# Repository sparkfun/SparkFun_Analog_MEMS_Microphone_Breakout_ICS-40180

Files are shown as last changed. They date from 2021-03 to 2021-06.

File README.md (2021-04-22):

SparkFun MEMS Microphone Breakout ICS-40180
========================================

SparkFun MEMS Microphone Breakout (ICS-40180) (https://www.sparkfun.com/products/18011)

[*SparkFun MEMS Microphone Breakout (ICS-40180) [BOB-18011]*](https://www.sparkfun.com/products/18011)

The SparkFun Analog MEMS Microphone Breakout makes it easy to work with the InvenSense ICS-40180 analog microphone. This board features an OpAmp to bring output of the microphone to a usable level, allowing you to plug directly into an ADC on a microcontroller or something like the [SparkFun Spectrum Shield](https://www.sparkfun.com/products/13116).

In addition to amplifying the signal, the OpAmp adds a bias voltage of 1/2 VCC. With sound sources such as a normal speaking voice a few feet away from the microphone, the AUD output signal will be at about 200mV peak-to-peak. Also note, this low profile microphone has its port on the bottom side, so the microphone can be mounted flush to the outer surface of your enclosure. This microphone is omni-directional, which means it does a good job of picking up sound sources from all directions.

Repository Contents
-------------------

* **/Documentation** - Data sheets, additional product information
* **/Hardware** - Eagle design files (.brd, .sch)
* **/Hardware/Production** - Production panel files (.brd)

Documentation
--------------
* **[Hookup Guide](https://learn.sparkfun.com/tutorials/mems-microphone-hookup-guide)** - Basic hookup guide for the SparkFun MEMS microphone breakout.

License Information
-------------------

This product is _**open source**_! 

Please review the LICENSE.md file for license information. 

If you have any questions or concerns on licensing, please contact technical support on our [SparkFun forums](https://forum.sparkfun.com/viewforum.php?f=152).

Distributed as-is; no warranty is given.

- Your friends at SparkFun.

_<COLLABORATION CREDIT>_

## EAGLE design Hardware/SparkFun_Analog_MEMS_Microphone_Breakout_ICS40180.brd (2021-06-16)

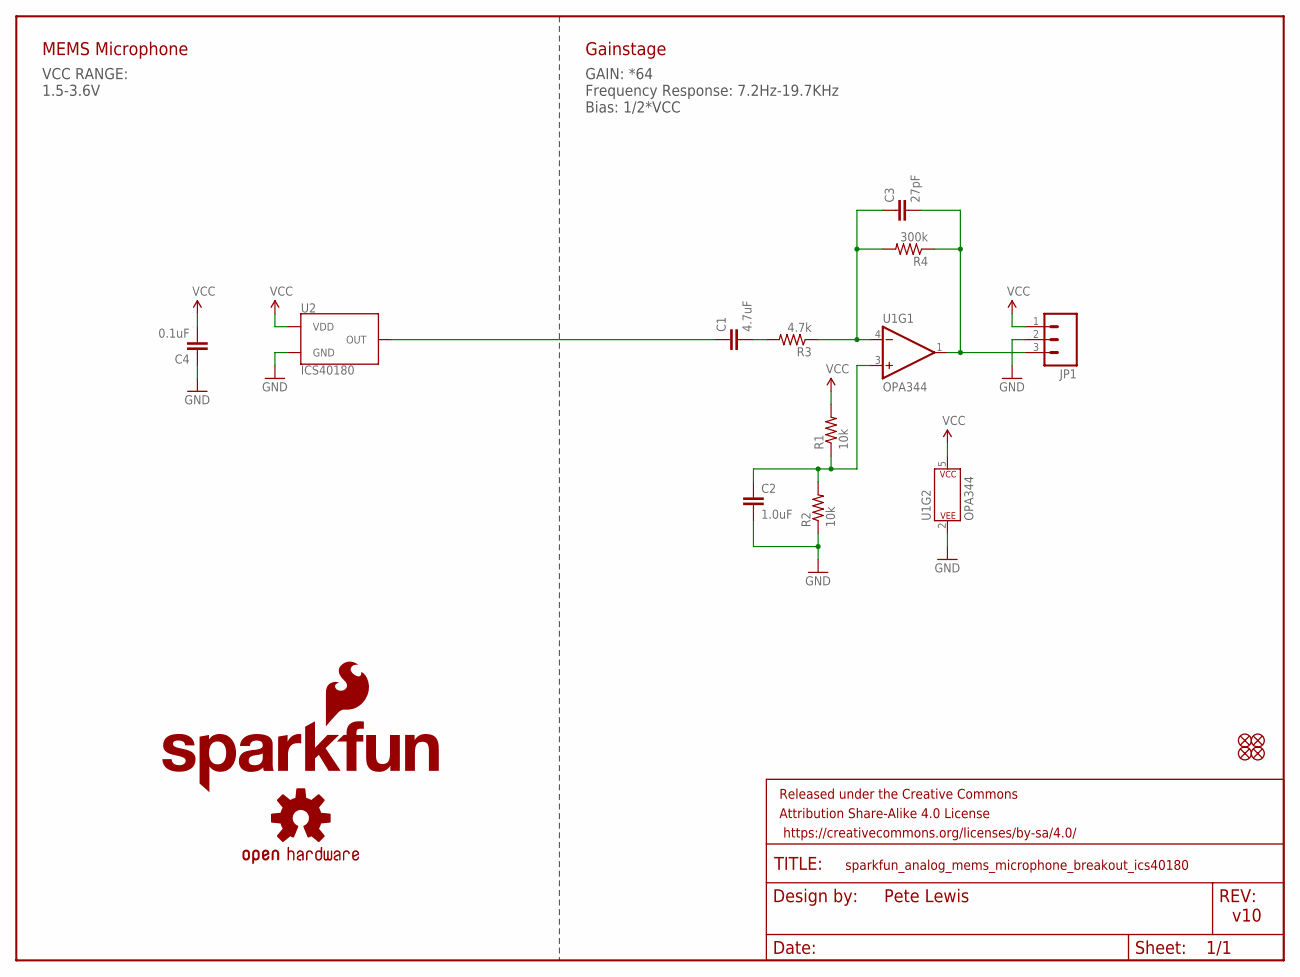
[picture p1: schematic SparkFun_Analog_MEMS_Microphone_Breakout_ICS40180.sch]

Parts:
C1: 4.7uF; 0603
C2: 1.0uF; 0603
C3: 27pF; 0603
C4: 0.1uF; 0603
FD1, FD2, FD3, FD4: FIDUCIALUFIDUCIAL; FIDUCIAL-MICRO
FRAME2: FRAME-LETTER; CREATIVE_COMMONS
JP1: CONN_031X03_NO_SILK; 1X03_NO_SILK
LOGO1: SFE_LOGO_FLAME.1_INCH; SFE_LOGO_FLAME_.1
LOGO2: OSHW-LOGOMINI; OSHW-LOGO-MINI
R1, R2: 10k; 0603
R3: 4.7k; 0603
R4: 300k; 0603
U1: OPA344; SOT23-5
U2: ICS40180

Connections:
AUD: C3.2, JP1.3, R4.1, U1.1 (OUT)
GND: C2.2, C4.1, JP1.2, R2.1, U1.2 (P$V-), U2.2 (GND), U2.3 (GND), U2.4 (GND)
unnamed: C1.1, U2.1 (OUT)
unnamed: C3.1, R3.1, R4.2, U1.4 (-IN)
unnamed: C1.2, R3.2
unnamed: C2.1, R1.1, R2.2, U1.3 (+IN)
VCC: C4.2, JP1.1, R1.2, U1.5 (P$V+), U2.5 (VDD)

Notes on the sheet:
v10
Pete Lewis
VCC RANGE: 1.5-3.6V
MEMS Microphone
Gainstage
GAIN: *64 Frequency Response: 7.2Hz-19.7KHz Bias: 1/2*VCC

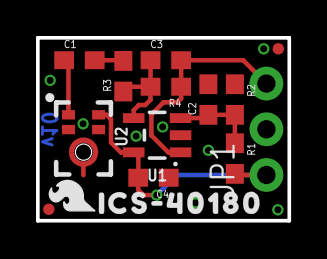
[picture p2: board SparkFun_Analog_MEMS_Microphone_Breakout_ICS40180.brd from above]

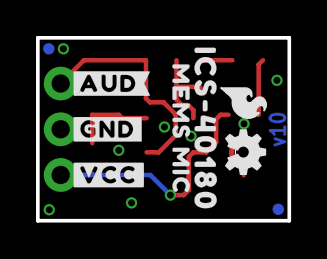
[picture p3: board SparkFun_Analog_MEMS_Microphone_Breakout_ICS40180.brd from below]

Board: 2 copper layers, 14.0 x 10.2 mm, 25 parts (9 on the bottom side), 7 nets.

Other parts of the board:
LOGO3: SFE_LOGO_FLAME.1_INCH; SFE_LOGO_FLAME_.1
U$1, U$6: ICS#401800
U$2: MEMS_MIC0
U$3: #GND#0
U$4: #VCC#0
U$5: #AUD#0

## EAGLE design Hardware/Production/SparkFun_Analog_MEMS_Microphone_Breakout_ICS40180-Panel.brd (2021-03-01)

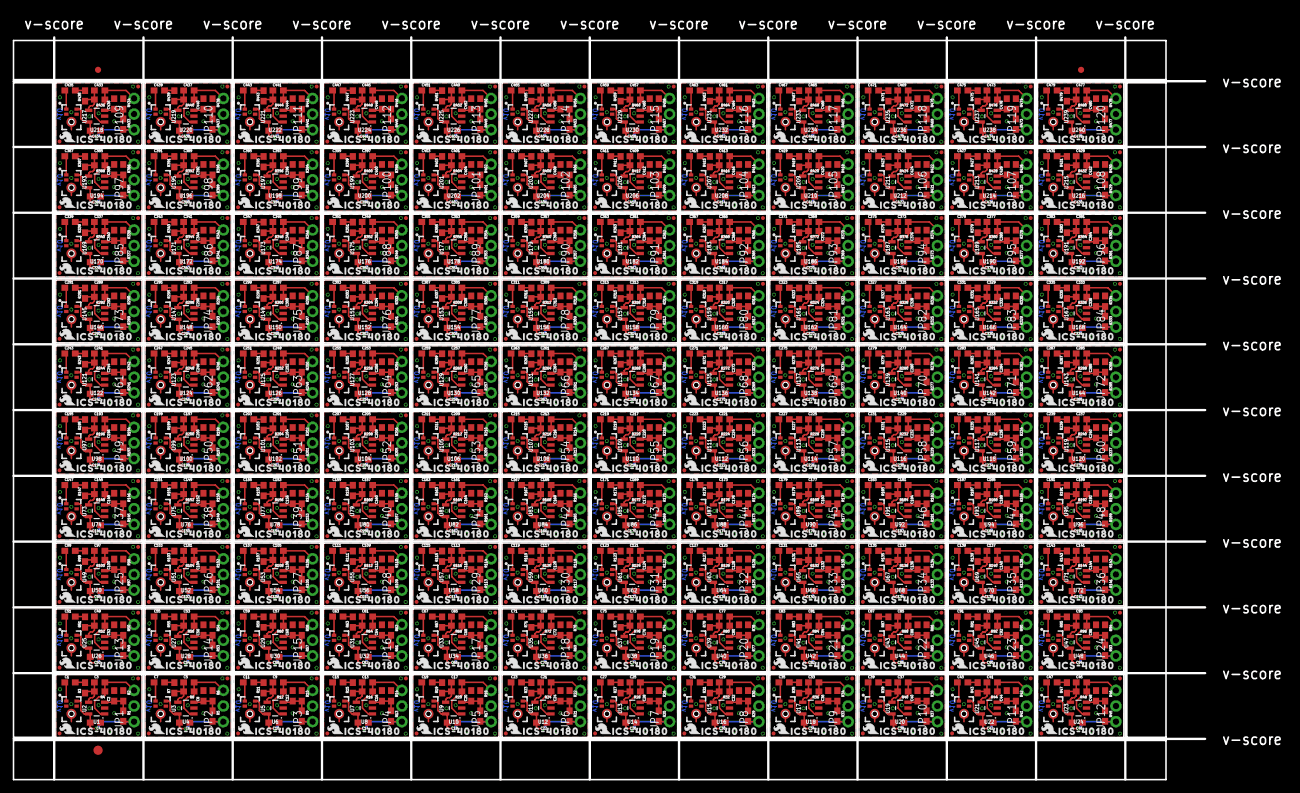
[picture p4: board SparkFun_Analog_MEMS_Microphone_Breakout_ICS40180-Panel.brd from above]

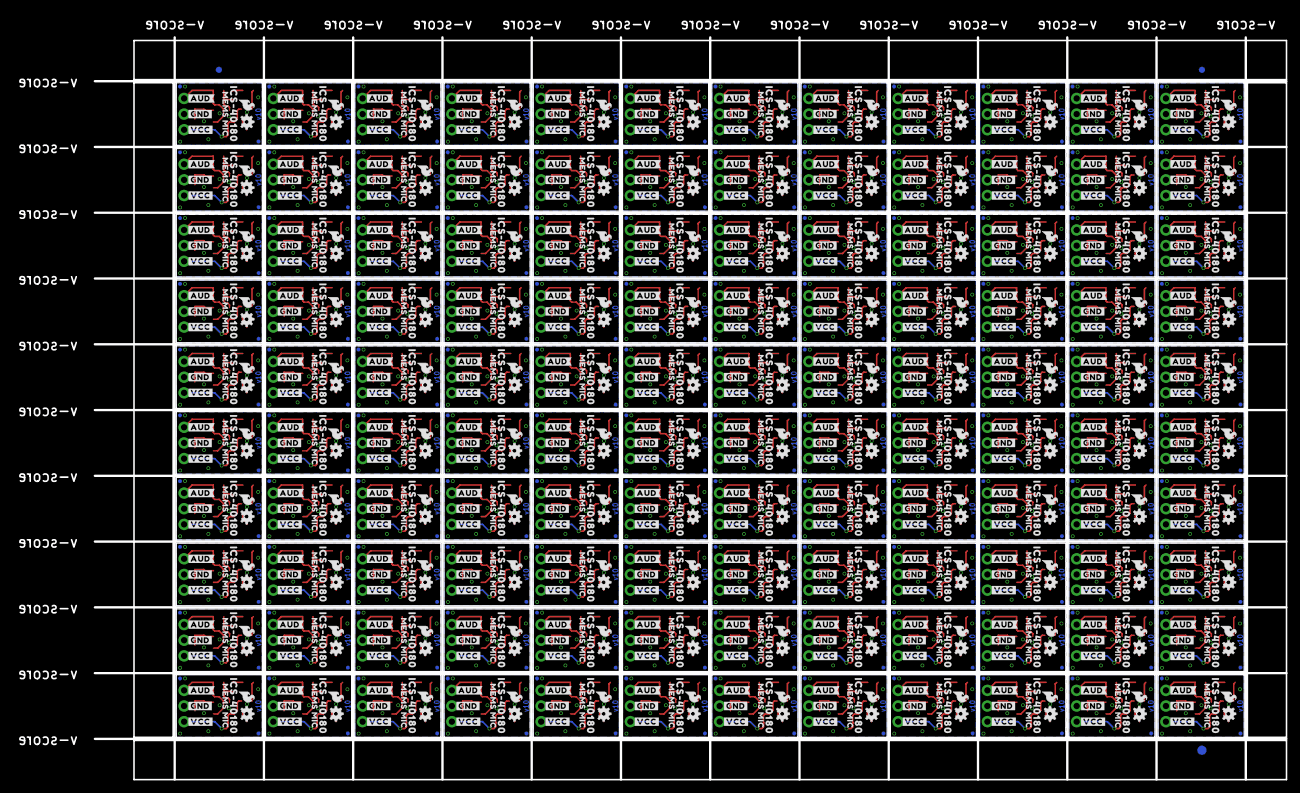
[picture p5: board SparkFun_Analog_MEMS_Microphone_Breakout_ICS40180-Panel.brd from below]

Board: 2 copper layers, 193.3 x 120.4 mm, 2886 parts (1083 on the bottom side), 840 nets.

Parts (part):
C1, C7, C11, C15, C19, C23, C27, C31, C35, C39, C43, C47, C51, C55, C59, C63, C67, C71, C75, C79, C83, C87, C91, C95, C99, C103, C107, C111, C115, C119, C123, C127, C131, C135, C139, C143, C147, C151, C155, C159, C163, C167, C171, C175, C179, C183, C187, C191, C195, C199, C203, C207, C211, C215, C219, C223, C227, C231, C235, C239, C243, C247, C251, C255, C259, C263, C267, C271, C275, C279, C283, C287, C291, C295, C299, C303, C307, C311, C315, C319, C323, C327, C331, C335, C339, C343, C347, C351, C355, C359, C363, C367, C371, C375, C379, C383, C387, C391, C395, C399, C403, C407, C411, C415, C419, C423, C427, C431, C435, C439, C443, C447, C451, C455, C459, C463, C467, C471, C475, C479: 4.7uF; 0603
C2, C8, C12, C16, C20, C24, C28, C32, C36, C40, C44, C48, C52, C56, C60, C64, C68, C72, C76, C80, C84, C88, C92, C96, C100, C104, C108, C112, C116, C120, C124, C128, C132, C136, C140, C144, C148, C152, C156, C160, C164, C168, C172, C176, C180, C184, C188, C192, C196, C200, C204, C208, C212, C216, C220, C224, C228, C232, C236, C240, C244, C248, C252, C256, C260, C264, C268, C272, C276, C280, C284, C288, C292, C296, C300, C304, C308, C312, C316, C320, C324, C328, C332, C336, C340, C344, C348, C352, C356, C360, C364, C368, C372, C376, C380, C384, C388, C392, C396, C400, C404, C408, C412, C416, C420, C424, C428, C432, C436, C440, C444, C448, C452, C456, C460, C464, C468, C472, C476, C480: 1.0uF; 0603
C3, C5, C9, C13, C17, C21, C25, C29, C33, C37, C41, C45, C49, C53, C57, C61, C65, C69, C73, C77, C81, C85, C89, C93, C97, C101, C105, C109, C113, C117, C121, C125, C129, C133, C137, C141, C145, C149, C153, C157, C161, C165, C169, C173, C177, C181, C185, C189, C193, C197, C201, C205, C209, C213, C217, C221, C225, C229, C233, C237, C241, C245, C249, C253, C257, C261, C265, C269, C273, C277, C281, C285, C289, C293, C297, C301, C305, C309, C313, C317, C321, C325, C329, C333, C337, C341, C345, C349, C353, C357, C361, C365, C369, C373, C377, C381, C385, C389, C393, C397, C401, C405, C409, C413, C417, C421, C425, C429, C433, C437, C441, C445, C449, C453, C457, C461, C465, C469, C473, C477: 27pF; 0603
C4, C6, C10, C14, C18, C22, C26, C30, C34, C38, C42, C46, C50, C54, C58, C62, C66, C70, C74, C78, C82, C86, C90, C94, C98, C102, C106, C110, C114, C118, C122, C126, C130, C134, C138, C142, C146, C150, C154, C158, C162, C166, C170, C174, C178, C182, C186, C190, C194, C198, C202, C206, C210, C214, C218, C222, C226, C230, C234, C238, C242, C246, C250, C254, C258, C262, C266, C270, C274, C278, C282, C286, C290, C294, C298, C302, C306, C310, C314, C318, C322, C326, C330, C334, C338, C342, C346, C350, C354, C358, C362, C366, C370, C374, C378, C382, C386, C390, C394, C398, C402, C406, C410, C414, C418, C422, C426, C430, C434, C438, C442, C446, C450, C454, C458, C462, C466, C470, C474, C478: 0.1uF; 0603
E$1, E$2, E$3, E$4: FIDUCIAL-1X2
E$5, E$6: FIDUCIAL-1.5X3
FD1, FD2, FD3, FD4, FD5, FD6, FD7, FD8, FD9, FD10, FD11, FD12, FD13, FD14, FD15, FD16, FD17, FD18, FD19, FD20, FD21, FD22, FD23, FD24, FD25, FD26, FD27, FD28, FD29, FD30, FD31, FD32, FD33, FD34, FD35, FD36, FD37, FD38, FD39, FD40, FD41, FD42, FD43, FD44, FD45, FD46, FD47, FD48, FD49, FD50, FD51, FD52, FD53, FD54, FD55, FD56, FD57, FD58, FD59, FD60, FD61, FD62, FD63, FD64, FD65, FD66, FD67, FD68, FD69, FD70, FD71, FD72, FD73, FD74, FD75, FD76, FD77, FD78, FD79, FD80, FD81, FD82, FD83, FD84, FD85, FD86, FD87, FD88, FD89, FD90, FD91, FD92, FD93, FD94, FD95, FD96, FD97, FD98, FD99, FD100, FD101, FD102, FD103, FD104, FD105, FD106, FD107, FD108, FD109, FD110, FD111, FD112, FD113, FD114, FD115, FD116, FD117, FD118, FD119, FD120, FD121, FD122, FD123, FD124, FD125, FD126, FD127, FD128, FD129, FD130, FD131, FD132, FD133, FD134, FD135, FD136, FD137, FD138, FD139, FD140, FD141, FD142, FD143, FD144, FD145, FD146, FD147, FD148, FD149, FD150, FD151, FD152, FD153, FD154, FD155, FD156, FD157, FD158, FD159, FD160, FD161, FD162, FD163, FD164, FD165, FD166, FD167, FD168, FD169, FD170, FD171, FD172, FD173, FD174, FD175, FD176, FD177, FD178, FD179, FD180, FD181, FD182, FD183, FD184, FD185, FD186, FD187, FD188, FD189, FD190, FD191, FD192, FD193, FD194, FD195, FD196, FD197, FD198, FD199, FD200, FD201, FD202, FD203, FD204, FD205, FD206, FD207, FD208, FD209, FD210, FD211, FD212, FD213, FD214, FD215, FD216, FD217, FD218, FD219, FD220, FD221, FD222, FD223, FD224, FD225, FD226, FD227, FD228, FD229, FD230, FD231, FD232, FD233, FD234, FD235, FD236, FD237, FD238, FD239, FD240, FD241, FD242, FD243, FD244, FD245, FD246, FD247, FD248, FD249, FD250, FD251, FD252, FD253, FD254, FD255, FD256, FD257, FD258, FD259, FD260, FD261, FD262, FD263, FD264, FD265, FD266, FD267, FD268, FD269, FD270, FD271, FD272, FD273, FD274, FD275, FD276, FD277, FD278, FD279, FD280, FD281, FD282, FD283, FD284, FD285, FD286, FD287, FD288, FD289, FD290, FD291, FD292, FD293, FD294, FD295, FD296, FD297, FD298, FD299, FD300, FD301, FD302, FD303, FD304, FD305, FD306, FD307, FD308, FD309, FD310, FD311, FD312, FD313, FD314, FD315, FD316, FD317, FD318, FD319, FD320, FD321, FD322, FD323, FD324, FD325, FD326, FD327, FD328, FD329, FD330, FD331, FD332, FD333, FD334, FD335, FD336, FD337, FD338, FD339, FD340, FD341, FD342, FD343, FD344, FD345, FD346, FD347, FD348, FD349, FD350, FD351, FD352, FD353, FD354, FD355, FD356, FD357, FD358, FD359, FD360, FD361, FD362, FD363, FD364, FD365, FD366, FD367, FD368, FD369, FD370, FD371, FD372, FD373, FD374, FD375, FD376, FD377, FD378, FD379, FD380, FD381, FD382, FD383, FD384, FD385, FD386, FD387, FD388, FD389, FD390, FD391, FD392, FD393, FD394, FD395, FD396, FD397, FD398, FD399, FD400, FD401, FD402, FD403, FD404, FD405, FD406, FD407, FD408, FD409, FD410, FD411, FD412, FD413, FD414, FD415, FD416, FD417, FD418, FD419, FD420, FD421, FD422, FD423, FD424, FD425, FD426, FD427, FD428, FD429, FD430, FD431, FD432, FD433, FD434, FD435, FD436, FD437, FD438, FD439, FD440, FD441, FD442, FD443, FD444, FD445, FD446, FD447, FD448, FD449, FD450, FD451, FD452, FD453, FD454, FD455, FD456, FD457, FD458, FD459, FD460, FD461, FD462, FD463, FD464, FD465, FD466, FD467, FD468, FD469, FD470, FD471, FD472, FD473, FD474, FD475, FD476, FD477, FD478, FD479, FD480: FIDUCIALUFIDUCIAL; FIDUCIAL-MICRO
JP1, JP2, JP3, JP4, JP5, JP6, JP7, JP8, JP9, JP10, JP11, JP12, JP13, JP14, JP15, JP16, JP17, JP18, JP19, JP20, JP21, JP22, JP23, JP24, JP25, JP26, JP27, JP28, JP29, JP30, JP31, JP32, JP33, JP34, JP35, JP36, JP37, JP38, JP39, JP40, JP41, JP42, JP43, JP44, JP45, JP46, JP47, JP48, JP49, JP50, JP51, JP52, JP53, JP54, JP55, JP56, JP57, JP58, JP59, JP60, JP61, JP62, JP63, JP64, JP65, JP66, JP67, JP68, JP69, JP70, JP71, JP72, JP73, JP74, JP75, JP76, JP77, JP78, JP79, JP80, JP81, JP82, JP83, JP84, JP85, JP86, JP87, JP88, JP89, JP90, JP91, JP92, JP93, JP94, JP95, JP96, JP97, JP98, JP99, JP100, JP101, JP102, JP103, JP104, JP105, JP106, JP107, JP108, JP109, JP110, JP111, JP112, JP113, JP114, JP115, JP116, JP117, JP118, JP119, JP120: 1X03_NO_SILK
LOGO1, LOGO3, LOGO4, LOGO6, LOGO7, LOGO9, LOGO10, LOGO12, LOGO13, LOGO15, LOGO16, LOGO18, LOGO19, LOGO21, LOGO22, LOGO24, LOGO25, LOGO27, LOGO28, LOGO30, LOGO31, LOGO33, LOGO34, LOGO36, LOGO37, LOGO39, LOGO40, LOGO42, LOGO43, LOGO45, LOGO46, LOGO48, LOGO49, LOGO51, LOGO52, LOGO54, LOGO55, LOGO57, LOGO58, LOGO60, LOGO61, LOGO63, LOGO64, LOGO66, LOGO67, LOGO69, LOGO70, LOGO72, LOGO73, LOGO75, LOGO76, LOGO78, LOGO79, LOGO81, LOGO82, LOGO84, LOGO85, LOGO87, LOGO88, LOGO90, LOGO91, LOGO93, LOGO94, LOGO96, LOGO97, LOGO99, LOGO100, LOGO102, LOGO103, LOGO105, LOGO106, LOGO108, LOGO109, LOGO111, LOGO112, LOGO114, LOGO115, LOGO117, LOGO118, LOGO120, LOGO121, LOGO123, LOGO124, LOGO126, LOGO127, LOGO129, LOGO130, LOGO132, LOGO133, LOGO135, LOGO136, LOGO138, LOGO139, LOGO141, LOGO142, LOGO144, LOGO145, LOGO147, LOGO148, LOGO150, LOGO151, LOGO153, LOGO154, LOGO156, LOGO157, LOGO159, LOGO160, LOGO162, LOGO163, LOGO165, LOGO166, LOGO168, LOGO169, LOGO171, LOGO172, LOGO174, LOGO175, LOGO177, LOGO178, LOGO180, LOGO181, LOGO183, LOGO184, LOGO186, LOGO187, LOGO189, LOGO190, LOGO192, LOGO193, LOGO195, LOGO196, LOGO198, LOGO199, LOGO201, LOGO202, LOGO204, LOGO205, LOGO207, LOGO208, LOGO210, LOGO211, LOGO213, LOGO214, LOGO216, LOGO217, LOGO219, LOGO220, LOGO222, LOGO223, LOGO225, LOGO226, LOGO228, LOGO229, LOGO231, LOGO232, LOGO234, LOGO235, LOGO237, LOGO238, LOGO240, LOGO241, LOGO243, LOGO244, LOGO246, LOGO247, LOGO249, LOGO250, LOGO252, LOGO253, LOGO255, LOGO256, LOGO258, LOGO259, LOGO261, LOGO262, LOGO264, LOGO265, LOGO267, LOGO268, LOGO270, LOGO271, LOGO273, LOGO274, LOGO276, LOGO277, LOGO279, LOGO280, LOGO282, LOGO283, LOGO285, LOGO286, LOGO288, LOGO289, LOGO291, LOGO292, LOGO294, LOGO295, LOGO297, LOGO298, LOGO300, LOGO301, LOGO303, LOGO304, LOGO306, LOGO307, LOGO309, LOGO310, LOGO312, LOGO313, LOGO315, LOGO316, LOGO318, LOGO319, LOGO321, LOGO322, LOGO324, LOGO325, LOGO327, LOGO328, LOGO330, LOGO331, LOGO333, LOGO334, LOGO336, LOGO337, LOGO339, LOGO340, LOGO342, LOGO343, LOGO345, LOGO346, LOGO348, LOGO349, LOGO351, LOGO352, LOGO354, LOGO355, LOGO357, LOGO358, LOGO360: SFE_LOGO_FLAME.1_INCH; SFE_LOGO_FLAME_.1
LOGO2, LOGO5, LOGO8, LOGO11, LOGO14, LOGO17, LOGO20, LOGO23, LOGO26, LOGO29, LOGO32, LOGO35, LOGO38, LOGO41, LOGO44, LOGO47, LOGO50, LOGO53, LOGO56, LOGO59, LOGO62, LOGO65, LOGO68, LOGO71, LOGO74, LOGO77, LOGO80, LOGO83, LOGO86, LOGO89, LOGO92, LOGO95, LOGO98, LOGO101, LOGO104, LOGO107, LOGO110, LOGO113, LOGO116, LOGO119, LOGO122, LOGO125, LOGO128, LOGO131, LOGO134, LOGO137, LOGO140, LOGO143, LOGO146, LOGO149, LOGO152, LOGO155, LOGO158, LOGO161, LOGO164, LOGO167, LOGO170, LOGO173, LOGO176, LOGO179, LOGO182, LOGO185, LOGO188, LOGO191, LOGO194, LOGO197, LOGO200, LOGO203, LOGO206, LOGO209, LOGO212, LOGO215, LOGO218, LOGO221, LOGO224, LOGO227, LOGO230, LOGO233, LOGO236, LOGO239, LOGO242, LOGO245, LOGO248, LOGO251, LOGO254, LOGO257, LOGO260, LOGO263, LOGO266, LOGO269, LOGO272, LOGO275, LOGO278, LOGO281, LOGO284, LOGO287, LOGO290, LOGO293, LOGO296, LOGO299, LOGO302, LOGO305, LOGO308, LOGO311, LOGO314, LOGO317, LOGO320, LOGO323, LOGO326, LOGO329, LOGO332, LOGO335, LOGO338, LOGO341, LOGO344, LOGO347, LOGO350, LOGO353, LOGO356, LOGO359: OSHW-LOGOMINI; OSHW-LOGO-MINI
R1, R2, R5, R6, R9, R10, R13, R14, R17, R18, R21, R22, R25, R26, R29, R30, R33, R34, R37, R38, R41, R42, R45, R46, R49, R50, R53, R54, R57, R58, R61, R62, R65, R66, R69, R70, R73, R74, R77, R78, R81, R82, R85, R86, R89, R90, R93, R94, R97, R98, R101, R102, R105, R106, R109, R110, R113, R114, R117, R118, R121, R122, R125, R126, R129, R130, R133, R134, R137, R138, R141, R142, R145, R146, R149, R150, R153, R154, R157, R158, R161, R162, R165, R166, R169, R170, R173, R174, R177, R178, R181, R182, R185, R186, R189, R190, R193, R194, R197, R198, R201, R202, R205, R206, R209, R210, R213, R214, R217, R218, R221, R222, R225, R226, R229, R230, R233, R234, R237, R238, R241, R242, R245, R246, R249, R250, R253, R254, R257, R258, R261, R262, R265, R266, R269, R270, R273, R274, R277, R278, R281, R282, R285, R286, R289, R290, R293, R294, R297, R298, R301, R302, R305, R306, R309, R310, R313, R314, R317, R318, R321, R322, R325, R326, R329, R330, R333, R334, R337, R338, R341, R342, R345, R346, R349, R350, R353, R354, R357, R358, R361, R362, R365, R366, R369, R370, R373, R374, R377, R378, R381, R382, R385, R386, R389, R390, R393, R394, R397, R398, R401, R402, R405, R406, R409, R410, R413, R414, R417, R418, R421, R422, R425, R426, R429, R430, R433, R434, R437, R438, R441, R442, R445, R446, R449, R450, R453, R454, R457, R458, R461, R462, R465, R466, R469, R470, R473, R474, R477, R478: 10k; 0603
R3, R7, R11, R15, R19, R23, R27, R31, R35, R39, R43, R47, R51, R55, R59, R63, R67, R71, R75, R79, R83, R87, R91, R95, R99, R103, R107, R111, R115, R119, R123, R127, R131, R135, R139, R143, R147, R151, R155, R159, R163, R167, R171, R175, R179, R183, R187, R191, R195, R199, R203, R207, R211, R215, R219, R223, R227, R231, R235, R239, R243, R247, R251, R255, R259, R263, R267, R271, R275, R279, R283, R287, R291, R295, R299, R303, R307, R311, R315, R319, R323, R327, R331, R335, R339, R343, R347, R351, R355, R359, R363, R367, R371, R375, R379, R383, R387, R391, R395, R399, R403, R407, R411, R415, R419, R423, R427, R431, R435, R439, R443, R447, R451, R455, R459, R463, R467, R471, R475, R479: 4.7k; 0603
R4, R8, R12, R16, R20, R24, R28, R32, R36, R40, R44, R48, R52, R56, R60, R64, R68, R72, R76, R80, R84, R88, R92, R96, R100, R104, R108, R112, R116, R120, R124, R128, R132, R136, R140, R144, R148, R152, R156, R160, R164, R168, R172, R176, R180, R184, R188, R192, R196, R200, R204, R208, R212, R216, R220, R224, R228, R232, R236, R240, R244, R248, R252, R256, R260, R264, R268, R272, R276, R280, R284, R288, R292, R296, R300, R304, R308, R312, R316, R320, R324, R328, R332, R336, R340, R344, R348, R352, R356, R360, R364, R368, R372, R376, R380, R384, R388, R392, R396, R400, R404, R408, R412, R416, R420, R424, R428, R432, R436, R440, R444, R448, R452, R456, R460, R464, R468, R472, R476, R480: 300k; 0603
U1, U4, U6, U8, U10, U12, U14, U16, U18, U20, U22, U24, U26, U28, U30, U32, U34, U36, U38, U40, U42, U44, U46, U48, U50, U52, U54, U56, U58, U60, U62, U64, U66, U68, U70, U72, U74, U76, U78, U80, U82, U84, U86, U88, U90, U92, U94, U96, U98, U100, U102, U104, U106, U108, U110, U112, U114, U116, U118, U120, U122, U124, U126, U128, U130, U132, U134, U136, U138, U140, U142, U144, U146, U148, U150, U152, U154, U156, U158, U160, U162, U164, U166, U168, U170, U172, U174, U176, U178, U180, U182, U184, U186, U188, U190, U192, U194, U196, U198, U200, U202, U204, U206, U208, U210, U212, U214, U216, U218, U220, U222, U224, U226, U228, U230, U232, U234, U236, U238, U240: OPA344; SOT23-5
U2, U3, U5, U7, U9, U11, U13, U15, U17, U19, U21, U23, U25, U27, U29, U31, U33, U35, U37, U39, U41, U43, U45, U47, U49, U51, U53, U55, U57, U59, U61, U63, U65, U67, U69, U71, U73, U75, U77, U79, U81, U83, U85, U87, U89, U91, U93, U95, U97, U99, U101, U103, U105, U107, U109, U111, U113, U115, U117, U119, U121, U123, U125, U127, U129, U131, U133, U135, U137, U139, U141, U143, U145, U147, U149, U151, U153, U155, U157, U159, U161, U163, U165, U167, U169, U171, U173, U175, U177, U179, U181, U183, U185, U187, U189, U191, U193, U195, U197, U199, U201, U203, U205, U207, U209, U211, U213, U215, U217, U219, U221, U223, U225, U227, U229, U231, U233, U235, U237, U239: ICS40180
U$1, U$6, U$7, U$12, U$13, U$18, U$19, U$24, U$25, U$30, U$31, U$36, U$37, U$42, U$43, U$48, U$49, U$54, U$55, U$60, U$61, U$66, U$67, U$72, U$73, U$78, U$79, U$84, U$85, U$90, U$91, U$96, U$97, U$102, U$103, U$108, U$109, U$114, U$115, U$120, U$121, U$126, U$127, U$132, U$133, U$138, U$139, U$144, U$145, U$150, U$151, U$156, U$157, U$162, U$163, U$168, U$169, U$174, U$175, U$180, U$181, U$186, U$187, U$192, U$193, U$198, U$199, U$204, U$205, U$210, U$211, U$216, U$217, U$222, U$223, U$228, U$229, U$234, U$235, U$240, U$241, U$246, U$247, U$252, U$253, U$258, U$259, U$264, U$265, U$270, U$271, U$276, U$277, U$282, U$283, U$288, U$289, U$294, U$295, U$300, U$301, U$306, U$307, U$312, U$313, U$318, U$319, U$324, U$325, U$330, U$331, U$336, U$337, U$342, U$343, U$348, U$349, U$354, U$355, U$360, U$361, U$366, U$367, U$372, U$373, U$378, U$379, U$384, U$385, U$390, U$391, U$396, U$397, U$402, U$403, U$408, U$409, U$414, U$415, U$420, U$421, U$426, U$427, U$432, U$433, U$438, U$439, U$444, U$445, U$450, U$451, U$456, U$457, U$462, U$463, U$468, U$469, U$474, U$475, U$480, U$481, U$486, U$487, U$492, U$493, U$498, U$499, U$504, U$505, U$510, U$511, U$516, U$517, U$522, U$523, U$528, U$529, U$534, U$535, U$540, U$541, U$546, U$547, U$552, U$553, U$558, U$559, U$564, U$565, U$570, U$571, U$576, U$577, U$582, U$583, U$588, U$589, U$594, U$595, U$600, U$601, U$606, U$607, U$612, U$613, U$618, U$619, U$624, U$625, U$630, U$631, U$636, U$637, U$642, U$643, U$648, U$649, U$654, U$655, U$660, U$661, U$666, U$667, U$672, U$673, U$678, U$679, U$684, U$685, U$690, U$691, U$696, U$697, U$702, U$703, U$708, U$709, U$714, U$715, U$720: ICS#401800
U$2, U$8, U$14, U$20, U$26, U$32, U$38, U$44, U$50, U$56, U$62, U$68, U$74, U$80, U$86, U$92, U$98, U$104, U$110, U$116, U$122, U$128, U$134, U$140, U$146, U$152, U$158, U$164, U$170, U$176, U$182, U$188, U$194, U$200, U$206, U$212, U$218, U$224, U$230, U$236, U$242, U$248, U$254, U$260, U$266, U$272, U$278, U$284, U$290, U$296, U$302, U$308, U$314, U$320, U$326, U$332, U$338, U$344, U$350, U$356, U$362, U$368, U$374, U$380, U$386, U$392, U$398, U$404, U$410, U$416, U$422, U$428, U$434, U$440, U$446, U$452, U$458, U$464, U$470, U$476, U$482, U$488, U$494, U$500, U$506, U$512, U$518, U$524, U$530, U$536, U$542, U$548, U$554, U$560, U$566, U$572, U$578, U$584, U$590, U$596, U$602, U$608, U$614, U$620, U$626, U$632, U$638, U$644, U$650, U$656, U$662, U$668, U$674, U$680, U$686, U$692, U$698, U$704, U$710, U$716: MEMS_MIC0
U$3, U$9, U$15, U$21, U$27, U$33, U$39, U$45, U$51, U$57, U$63, U$69, U$75, U$81, U$87, U$93, U$99, U$105, U$111, U$117, U$123, U$129, U$135, U$141, U$147, U$153, U$159, U$165, U$171, U$177, U$183, U$189, U$195, U$201, U$207, U$213, U$219, U$225, U$231, U$237, U$243, U$249, U$255, U$261, U$267, U$273, U$279, U$285, U$291, U$297, U$303, U$309, U$315, U$321, U$327, U$333, U$339, U$345, U$351, U$357, U$363, U$369, U$375, U$381, U$387, U$393, U$399, U$405, U$411, U$417, U$423, U$429, U$435, U$441, U$447, U$453, U$459, U$465, U$471, U$477, U$483, U$489, U$495, U$501, U$507, U$513, U$519, U$525, U$531, U$537, U$543, U$549, U$555, U$561, U$567, U$573, U$579, U$585, U$591, U$597, U$603, U$609, U$615, U$621, U$627, U$633, U$639, U$645, U$651, U$657, U$663, U$669, U$675, U$681, U$687, U$693, U$699, U$705, U$711, U$717: #GND#0
U$4, U$10, U$16, U$22, U$28, U$34, U$40, U$46, U$52, U$58, U$64, U$70, U$76, U$82, U$88, U$94, U$100, U$106, U$112, U$118, U$124, U$130, U$136, U$142, U$148, U$154, U$160, U$166, U$172, U$178, U$184, U$190, U$196, U$202, U$208, U$214, U$220, U$226, U$232, U$238, U$244, U$250, U$256, U$262, U$268, U$274, U$280, U$286, U$292, U$298, U$304, U$310, U$316, U$322, U$328, U$334, U$340, U$346, U$352, U$358, U$364, U$370, U$376, U$382, U$388, U$394, U$400, U$406, U$412, U$418, U$424, U$430, U$436, U$442, U$448, U$454, U$460, U$466, U$472, U$478, U$484, U$490, U$496, U$502, U$508, U$514, U$520, U$526, U$532, U$538, U$544, U$550, U$556, U$562, U$568, U$574, U$580, U$586, U$592, U$598, U$604, U$610, U$616, U$622, U$628, U$634, U$640, U$646, U$652, U$658, U$664, U$670, U$676, U$682, U$688, U$694, U$700, U$706, U$712, U$718: #VCC#0
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

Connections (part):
AUD: C3.2, JP1.3, R4.1, U1.1
AUD1: C5.2, JP2.3, R8.1, U4.1
AUD2: C9.2, JP3.3, R12.1, U6.1
AUD3: C13.2, JP4.3, R16.1, U8.1
AUD4: C17.2, JP5.3, R20.1, U10.1
AUD5: C21.2, JP6.3, R24.1, U12.1
AUD6: C25.2, JP7.3, R28.1, U14.1
AUD7: C29.2, JP8.3, R32.1, U16.1
AUD8: C33.2, JP9.3, R36.1, U18.1
AUD9: C37.2, JP10.3, R40.1, U20.1
AUD10: C41.2, JP11.3, R44.1, U22.1
AUD11: C45.2, JP12.3, R48.1, U24.1
AUD12: C49.2, JP13.3, R52.1, U26.1
AUD13: C53.2, JP14.3, R56.1, U28.1
AUD14: C57.2, JP15.3, R60.1, U30.1
AUD15: C61.2, JP16.3, R64.1, U32.1
AUD16: C65.2, JP17.3, R68.1, U34.1
AUD17: C69.2, JP18.3, R72.1, U36.1
AUD18: C73.2, JP19.3, R76.1, U38.1
AUD19: C77.2, JP20.3, R80.1, U40.1
AUD20: C81.2, JP21.3, R84.1, U42.1
AUD21: C85.2, JP22.3, R88.1, U44.1
AUD22: C89.2, JP23.3, R92.1, U46.1
AUD23: C93.2, JP24.3, R96.1, U48.1
AUD24: C97.2, JP25.3, R100.1, U50.1
AUD25: C101.2, JP26.3, R104.1, U52.1
AUD26: C105.2, JP27.3, R108.1, U54.1
AUD27: C109.2, JP28.3, R112.1, U56.1
AUD28: C113.2, JP29.3, R116.1, U58.1
AUD29: C117.2, JP30.3, R120.1, U60.1
AUD30: C121.2, JP31.3, R124.1, U62.1
AUD31: C125.2, JP32.3, R128.1, U64.1
AUD32: C129.2, JP33.3, R132.1, U66.1
AUD33: C133.2, JP34.3, R136.1, U68.1
AUD34: C137.2, JP35.3, R140.1, U70.1
AUD35: C141.2, JP36.3, R144.1, U72.1
AUD36: C145.2, JP37.3, R148.1, U74.1
AUD37: C149.2, JP38.3, R152.1, U76.1
AUD38: C153.2, JP39.3, R156.1, U78.1
AUD39: C157.2, JP40.3, R160.1, U80.1
AUD40: C161.2, JP41.3, R164.1, U82.1
AUD41: C165.2, JP42.3, R168.1, U84.1
AUD42: C169.2, JP43.3, R172.1, U86.1
AUD43: C173.2, JP44.3, R176.1, U88.1
AUD44: C177.2, JP45.3, R180.1, U90.1
AUD45: C181.2, JP46.3, R184.1, U92.1
AUD46: C185.2, JP47.3, R188.1, U94.1
AUD47: C189.2, JP48.3, R192.1, U96.1
AUD48: C193.2, JP49.3, R196.1, U98.1
AUD49: C197.2, JP50.3, R200.1, U100.1
AUD50: C201.2, JP51.3, R204.1, U102.1
AUD51: C205.2, JP52.3, R208.1, U104.1
AUD52: C209.2, JP53.3, R212.1, U106.1
AUD53: C213.2, JP54.3, R216.1, U108.1
AUD54: C217.2, JP55.3, R220.1, U110.1
AUD55: C221.2, JP56.3, R224.1, U112.1
AUD56: C225.2, JP57.3, R228.1, U114.1
AUD57: C229.2, JP58.3, R232.1, U116.1
AUD58: C233.2, JP59.3, R236.1, U118.1
AUD59: C237.2, JP60.3, R240.1, U120.1
AUD60: C241.2, JP61.3, R244.1, U122.1
AUD61: C245.2, JP62.3, R248.1, U124.1
AUD62: C249.2, JP63.3, R252.1, U126.1
AUD63: C253.2, JP64.3, R256.1, U128.1
AUD64: C257.2, JP65.3, R260.1, U130.1
AUD65: C261.2, JP66.3, R264.1, U132.1
AUD66: C265.2, JP67.3, R268.1, U134.1
AUD67: C269.2, JP68.3, R272.1, U136.1
AUD68: C273.2, JP69.3, R276.1, U138.1
AUD69: C277.2, JP70.3, R280.1, U140.1
AUD70: C281.2, JP71.3, R284.1, U142.1
AUD71: C285.2, JP72.3, R288.1, U144.1
AUD72: C289.2, JP73.3, R292.1, U146.1
AUD73: C293.2, JP74.3, R296.1, U148.1
AUD74: C297.2, JP75.3, R300.1, U150.1
AUD75: C301.2, JP76.3, R304.1, U152.1
AUD76: C305.2, JP77.3, R308.1, U154.1
AUD77: C309.2, JP78.3, R312.1, U156.1
AUD78: C313.2, JP79.3, R316.1, U158.1
AUD79: C317.2, JP80.3, R320.1, U160.1
AUD80: C321.2, JP81.3, R324.1, U162.1
AUD81: C325.2, JP82.3, R328.1, U164.1
AUD82: C329.2, JP83.3, R332.1, U166.1
AUD83: C333.2, JP84.3, R336.1, U168.1
AUD84: C337.2, JP85.3, R340.1, U170.1
AUD85: C341.2, JP86.3, R344.1, U172.1
AUD86: C345.2, JP87.3, R348.1, U174.1
AUD87: C349.2, JP88.3, R352.1, U176.1
AUD88: C353.2, JP89.3, R356.1, U178.1
AUD89: C357.2, JP90.3, R360.1, U180.1
AUD90: C361.2, JP91.3, R364.1, U182.1
AUD91: C365.2, JP92.3, R368.1, U184.1
AUD92: C369.2, JP93.3, R372.1, U186.1
AUD93: C373.2, JP94.3, R376.1, U188.1
AUD94: C377.2, JP95.3, R380.1, U190.1
AUD95: C381.2, JP96.3, R384.1, U192.1
AUD96: C385.2, JP97.3, R388.1, U194.1
AUD97: C389.2, JP98.3, R392.1, U196.1
AUD98: C393.2, JP99.3, R396.1, U198.1
AUD99: C397.2, JP100.3, R400.1, U200.1
AUD100: C401.2, JP101.3, R404.1, U202.1
AUD101: C405.2, JP102.3, R408.1, U204.1
AUD102: C409.2, JP103.3, R412.1, U206.1
AUD103: C413.2, JP104.3, R416.1, U208.1
AUD104: C417.2, JP105.3, R420.1, U210.1
AUD105: C421.2, JP106.3, R424.1, U212.1
AUD106: C425.2, JP107.3, R428.1, U214.1
AUD107: C429.2, JP108.3, R432.1, U216.1
AUD108: C433.2, JP109.3, R436.1, U218.1
AUD109: C437.2, JP110.3, R440.1, U220.1
AUD110: C441.2, JP111.3, R444.1, U222.1
AUD111: C445.2, JP112.3, R448.1, U224.1
AUD112: C449.2, JP113.3, R452.1, U226.1
AUD113: C453.2, JP114.3, R456.1, U228.1
AUD114: C457.2, JP115.3, R460.1, U230.1
AUD115: C461.2, JP116.3, R464.1, U232.1
AUD116: C465.2, JP117.3, R468.1, U234.1
AUD117: C469.2, JP118.3, R472.1, U236.1
AUD118: C473.2, JP119.3, R476.1, U238.1
AUD119: C477.2, JP120.3, R480.1, U240.1
GND: C2.2, C4.1, JP1.2, R2.1, U1.2, U2.2, U2.3, U2.4
GND1: C6.1, C8.2, JP2.2, R6.1, U3.2, U3.3, U3.4, U4.2
GND2: C10.1, C12.2, JP3.2, R10.1, U5.2, U5.3, U5.4, U6.2
GND3: C14.1, C16.2, JP4.2, R14.1, U7.2, U7.3, U7.4, U8.2
GND4: C18.1, C20.2, JP5.2, R18.1, U9.2, U9.3, U9.4, U10.2
GND5: C22.1, C24.2, JP6.2, R22.1, U11.2, U11.3, U11.4, U12.2
GND6: C26.1, C28.2, JP7.2, R26.1, U13.2, U13.3, U13.4, U14.2
GND7: C30.1, C32.2, JP8.2, R30.1, U15.2, U15.3, U15.4, U16.2
GND8: C34.1, C36.2, JP9.2, R34.1, U17.2, U17.3, U17.4, U18.2
GND9: C38.1, C40.2, JP10.2, R38.1, U19.2, U19.3, U19.4, U20.2
GND10: C42.1, C44.2, JP11.2, R42.1, U21.2, U21.3, U21.4, U22.2
GND11: C46.1, C48.2, JP12.2, R46.1, U23.2, U23.3, U23.4, U24.2
GND12: C50.1, C52.2, JP13.2, R50.1, U25.2, U25.3, U25.4, U26.2
GND13: C54.1, C56.2, JP14.2, R54.1, U27.2, U27.3, U27.4, U28.2
GND14: C58.1, C60.2, JP15.2, R58.1, U29.2, U29.3, U29.4, U30.2
GND15: C62.1, C64.2, JP16.2, R62.1, U31.2, U31.3, U31.4, U32.2
GND16: C66.1, C68.2, JP17.2, R66.1, U33.2, U33.3, U33.4, U34.2
GND17: C70.1, C72.2, JP18.2, R70.1, U35.2, U35.3, U35.4, U36.2
GND18: C74.1, C76.2, JP19.2, R74.1, U37.2, U37.3, U37.4, U38.2
GND19: C78.1, C80.2, JP20.2, R78.1, U39.2, U39.3, U39.4, U40.2
GND20: C82.1, C84.2, JP21.2, R82.1, U41.2, U41.3, U41.4, U42.2
GND21: C86.1, C88.2, JP22.2, R86.1, U43.2, U43.3, U43.4, U44.2
GND22: C90.1, C92.2, JP23.2, R90.1, U45.2, U45.3, U45.4, U46.2
GND23: C94.1, C96.2, JP24.2, R94.1, U47.2, U47.3, U47.4, U48.2
GND24: C98.1, C100.2, JP25.2, R98.1, U49.2, U49.3, U49.4, U50.2
GND25: C102.1, C104.2, JP26.2, R102.1, U51.2, U51.3, U51.4, U52.2
GND26: C106.1, C108.2, JP27.2, R106.1, U53.2, U53.3, U53.4, U54.2
GND27: C110.1, C112.2, JP28.2, R110.1, U55.2, U55.3, U55.4, U56.2
GND28: C114.1, C116.2, JP29.2, R114.1, U57.2, U57.3, U57.4, U58.2
GND29: C118.1, C120.2, JP30.2, R118.1, U59.2, U59.3, U59.4, U60.2
GND30: C122.1, C124.2, JP31.2, R122.1, U61.2, U61.3, U61.4, U62.2
GND31: C126.1, C128.2, JP32.2, R126.1, U63.2, U63.3, U63.4, U64.2
GND32: C130.1, C132.2, JP33.2, R130.1, U65.2, U65.3, U65.4, U66.2
GND33: C134.1, C136.2, JP34.2, R134.1, U67.2, U67.3, U67.4, U68.2
GND34: C138.1, C140.2, JP35.2, R138.1, U69.2, U69.3, U69.4, U70.2
GND35: C142.1, C144.2, JP36.2, R142.1, U71.2, U71.3, U71.4, U72.2
GND36: C146.1, C148.2, JP37.2, R146.1, U73.2, U73.3, U73.4, U74.2
GND37: C150.1, C152.2, JP38.2, R150.1, U75.2, U75.3, U75.4, U76.2
GND38: C154.1, C156.2, JP39.2, R154.1, U77.2, U77.3, U77.4, U78.2
GND39: C158.1, C160.2, JP40.2, R158.1, U79.2, U79.3, U79.4, U80.2
GND40: C162.1, C164.2, JP41.2, R162.1, U81.2, U81.3, U81.4, U82.2
GND41: C166.1, C168.2, JP42.2, R166.1, U83.2, U83.3, U83.4, U84.2
GND42: C170.1, C172.2, JP43.2, R170.1, U85.2, U85.3, U85.4, U86.2
GND43: C174.1, C176.2, JP44.2, R174.1, U87.2, U87.3, U87.4, U88.2
GND44: C178.1, C180.2, JP45.2, R178.1, U89.2, U89.3, U89.4, U90.2
GND45: C182.1, C184.2, JP46.2, R182.1, U91.2, U91.3, U91.4, U92.2
GND46: C186.1, C188.2, JP47.2, R186.1, U93.2, U93.3, U93.4, U94.2
GND47: C190.1, C192.2, JP48.2, R190.1, U95.2, U95.3, U95.4, U96.2
GND48: C194.1, C196.2, JP49.2, R194.1, U97.2, U97.3, U97.4, U98.2
GND49: C198.1, C200.2, JP50.2, R198.1, U99.2, U99.3, U99.4, U100.2
GND50: C202.1, C204.2, JP51.2, R202.1, U101.2, U101.3, U101.4, U102.2
GND51: C206.1, C208.2, JP52.2, R206.1, U103.2, U103.3, U103.4, U104.2
GND52: C210.1, C212.2, JP53.2, R210.1, U105.2, U105.3, U105.4, U106.2
GND53: C214.1, C216.2, JP54.2, R214.1, U107.2, U107.3, U107.4, U108.2
GND54: C218.1, C220.2, JP55.2, R218.1, U109.2, U109.3, U109.4, U110.2
GND55: C222.1, C224.2, JP56.2, R222.1, U111.2, U111.3, U111.4, U112.2
GND56: C226.1, C228.2, JP57.2, R226.1, U113.2, U113.3, U113.4, U114.2
GND57: C230.1, C232.2, JP58.2, R230.1, U115.2, U115.3, U115.4, U116.2
GND58: C234.1, C236.2, JP59.2, R234.1, U117.2, U117.3, U117.4, U118.2
GND59: C238.1, C240.2, JP60.2, R238.1, U119.2, U119.3, U119.4, U120.2
GND60: C242.1, C244.2, JP61.2, R242.1, U121.2, U121.3, U121.4, U122.2
GND61: C246.1, C248.2, JP62.2, R246.1, U123.2, U123.3, U123.4, U124.2
GND62: C250.1, C252.2, JP63.2, R250.1, U125.2, U125.3, U125.4, U126.2
GND63: C254.1, C256.2, JP64.2, R254.1, U127.2, U127.3, U127.4, U128.2
GND64: C258.1, C260.2, JP65.2, R258.1, U129.2, U129.3, U129.4, U130.2
GND65: C262.1, C264.2, JP66.2, R262.1, U131.2, U131.3, U131.4, U132.2
GND66: C266.1, C268.2, JP67.2, R266.1, U133.2, U133.3, U133.4, U134.2
GND67: C270.1, C272.2, JP68.2, R270.1, U135.2, U135.3, U135.4, U136.2
GND68: C274.1, C276.2, JP69.2, R274.1, U137.2, U137.3, U137.4, U138.2
GND69: C278.1, C280.2, JP70.2, R278.1, U139.2, U139.3, U139.4, U140.2
GND70: C282.1, C284.2, JP71.2, R282.1, U141.2, U141.3, U141.4, U142.2
GND71: C286.1, C288.2, JP72.2, R286.1, U143.2, U143.3, U143.4, U144.2
GND72: C290.1, C292.2, JP73.2, R290.1, U145.2, U145.3, U145.4, U146.2
GND73: C294.1, C296.2, JP74.2, R294.1, U147.2, U147.3, U147.4, U148.2
GND74: C298.1, C300.2, JP75.2, R298.1, U149.2, U149.3, U149.4, U150.2
GND75: C302.1, C304.2, JP76.2, R302.1, U151.2, U151.3, U151.4, U152.2
GND76: C306.1, C308.2, JP77.2, R306.1, U153.2, U153.3, U153.4, U154.2
GND77: C310.1, C312.2, JP78.2, R310.1, U155.2, U155.3, U155.4, U156.2
GND78: C314.1, C316.2, JP79.2, R314.1, U157.2, U157.3, U157.4, U158.2
GND79: C318.1, C320.2, JP80.2, R318.1, U159.2, U159.3, U159.4, U160.2
GND80: C322.1, C324.2, JP81.2, R322.1, U161.2, U161.3, U161.4, U162.2
GND81: C326.1, C328.2, JP82.2, R326.1, U163.2, U163.3, U163.4, U164.2
GND82: C330.1, C332.2, JP83.2, R330.1, U165.2, U165.3, U165.4, U166.2
GND83: C334.1, C336.2, JP84.2, R334.1, U167.2, U167.3, U167.4, U168.2
GND84: C338.1, C340.2, JP85.2, R338.1, U169.2, U169.3, U169.4, U170.2
GND85: C342.1, C344.2, JP86.2, R342.1, U171.2, U171.3, U171.4, U172.2
GND86: C346.1, C348.2, JP87.2, R346.1, U173.2, U173.3, U173.4, U174.2
GND87: C350.1, C352.2, JP88.2, R350.1, U175.2, U175.3, U175.4, U176.2
GND88: C354.1, C356.2, JP89.2, R354.1, U177.2, U177.3, U177.4, U178.2
GND89: C358.1, C360.2, JP90.2, R358.1, U179.2, U179.3, U179.4, U180.2
GND90: C362.1, C364.2, JP91.2, R362.1, U181.2, U181.3, U181.4, U182.2
GND91: C366.1, C368.2, JP92.2, R366.1, U183.2, U183.3, U183.4, U184.2
GND92: C370.1, C372.2, JP93.2, R370.1, U185.2, U185.3, U185.4, U186.2
GND93: C374.1, C376.2, JP94.2, R374.1, U187.2, U187.3, U187.4, U188.2
GND94: C378.1, C380.2, JP95.2, R378.1, U189.2, U189.3, U189.4, U190.2
GND95: C382.1, C384.2, JP96.2, R382.1, U191.2, U191.3, U191.4, U192.2
GND96: C386.1, C388.2, JP97.2, R386.1, U193.2, U193.3, U193.4, U194.2
GND97: C390.1, C392.2, JP98.2, R390.1, U195.2, U195.3, U195.4, U196.2
GND98: C394.1, C396.2, JP99.2, R394.1, U197.2, U197.3, U197.4, U198.2
GND99: C398.1, C400.2, JP100.2, R398.1, U199.2, U199.3, U199.4, U200.2
GND100: C402.1, C404.2, JP101.2, R402.1, U201.2, U201.3, U201.4, U202.2
GND101: C406.1, C408.2, JP102.2, R406.1, U203.2, U203.3, U203.4, U204.2
GND102: C410.1, C412.2, JP103.2, R410.1, U205.2, U205.3, U205.4, U206.2
GND103: C414.1, C416.2, JP104.2, R414.1, U207.2, U207.3, U207.4, U208.2
GND104: C418.1, C420.2, JP105.2, R418.1, U209.2, U209.3, U209.4, U210.2
GND105: C422.1, C424.2, JP106.2, R422.1, U211.2, U211.3, U211.4, U212.2
GND106: C426.1, C428.2, JP107.2, R426.1, U213.2, U213.3, U213.4, U214.2
GND107: C430.1, C432.2, JP108.2, R430.1, U215.2, U215.3, U215.4, U216.2
GND108: C434.1, C436.2, JP109.2, R434.1, U217.2, U217.3, U217.4, U218.2
GND109: C438.1, C440.2, JP110.2, R438.1, U219.2, U219.3, U219.4, U220.2
GND110: C442.1, C444.2, JP111.2, R442.1, U221.2, U221.3, U221.4, U222.2
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

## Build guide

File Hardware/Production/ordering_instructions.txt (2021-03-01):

panel size, 187x120mm
PCB thickness, 1.6mm
number of layers, 2
soldermask color, Red
silkscreen color, White
oz copper, 1oz
finish, HASL lead free
stencils, top
pcs per panel, 120
min trace width, 0.2540mm / 0.0100in
min drill size, 0.3810mm / 0.0150in

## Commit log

2021-02-16 initial layout
    [SparkFun_MEMs_Microphone_Breakout_ICS-40180.brd, SparkFun_MEMs_Microphone_Breakout_ICS-40180.sch]
2021-02-24 changed label to fish flag output on AUD pin
    added fiducials
    [SparkFun_MEMs_Microphone_Breakout_ICS-40180.brd, SparkFun_MEMs_Microphone_Breakout_ICS-40180.sch]
2021-02-26 Moved passives for tighter layout
    -Moved passives to tighten up traces near + and - inputs on op amp.
    -Added mic model # and flame to top silk
    -Added measures
    [SparkFun_MEMs_Microphone_Breakout_ICS-40180.brd]
2021-03-01 Changed values to extend freq response
    -Changes passives to extend frequency rolloffs on the opamp circuit. It's not 7.2Hz-19.7KHz, which better matches the capabilities of the new mic.
    -Added SparkFun "name" logo to schematic - note, I copied vectors from library so it isn't a proper symbol/device.
    -rearranged schematic and labeled "mic" and "gainstage" sections
    -Capitalized the S in MEMS on the bottom silk.
    -Made measures text size all the same at 0.05inch
    [SparkFun_MEMs_Microphone_Breakout_ICS-40180.brd, SparkFun_MEMs_Microphone_Breakout_ICS-40180.sch]
2021-03-01 capitalizing S in MEMS file name
    [SparkFun_MEMS_Microphone_Breakout_ICS40180.brd, SparkFun_MEMS_Microphone_Breakout_ICS40180.sch]
2021-03-01 name update
    [SparkFun_Analog_MEMS_Microphone_Breakout_ICS40180.brd, SparkFun_Analog_MEMS_Microphone_Breakout_ICS40180.sch]
2021-03-01 checklist updates
    -rearranged tName for assembly sheet
    -removed one stub
    -nudge a trace to allow better gnd flow.
    [SparkFun_Analog_MEMS_Microphone_Breakout_ICS40180.brd]
2021-03-01 Reduced paste on the mic FP
    -reduced both on the GND ring and the other 4 rectangular pads.
    [SparkFun_Analog_MEMS_Microphone_Breakout_ICS40180.brd, SparkFun_Analog_MEMS_Microphone_Breakout_ICS40180.sch]
2021-03-01 production panel gerbers v10
    [SparkFun_Analog_MEMS_Microphone_Breakout_ICS40180-Panel.brd]
2021-03-02 removed one measure that was unnecessary
    -we don't really need to show measure for each individual 0.1inch header, the spacing can be assumed as pitch of headers.
    [SparkFun_Analog_MEMS_Microphone_Breakout_ICS40180.brd]
2021-06-16 Migrating mic and VCC/GNDs to latest eagle libraries
    -Doesn't change design at all, but just makes it cleaner/easier to know where the devices live in our main eagle libraries repo.
    [SparkFun_Analog_MEMS_Microphone_Breakout_ICS40180.brd, SparkFun_Analog_MEMS_Microphone_Breakout_ICS40180.sch]

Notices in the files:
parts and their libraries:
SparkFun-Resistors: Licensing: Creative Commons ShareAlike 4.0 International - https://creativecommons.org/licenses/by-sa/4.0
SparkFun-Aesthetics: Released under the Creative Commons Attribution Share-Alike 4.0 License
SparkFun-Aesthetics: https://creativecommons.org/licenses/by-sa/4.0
